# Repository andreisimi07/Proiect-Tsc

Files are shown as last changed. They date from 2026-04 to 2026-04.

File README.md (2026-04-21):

# InkTime

Acest repository contine fisierele de design hardware, documentatia si detaliile de implementare pentru smartwatch. Inima sistemului este nRF52840 de la Nordic Semiconductor, ales pentru capabilitatile sale multiprotocol (Bluetooth LE, Thread, Zigbee) si consumul redus de energie.

## Schema Bloc

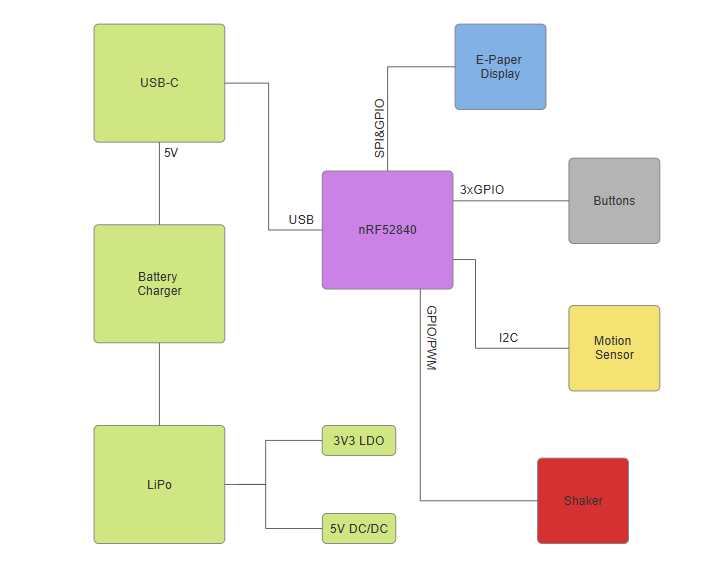
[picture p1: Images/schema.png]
Schema bloc


## Bill of Materials (BOM)

| Component | Description | Qty | Manufacturer | Part Number | Datasheet |
| :--- | :--- | :--- | :--- | :--- | :--- |
| **Microcontroller** | nRF52840 (AQFN-74) | 1 | Nordic Semiconductor | NRF52840_QF | [Link](https://files.seeedstudio.com/wiki/XIAO-BLE/Nano_BLE_MCU-nRF52840_PS_v1.1.pdf) |
| **Antenna** | 2.45GHz Chip Antenna | 1 | Johanson Technology | 2450AT18B100E | [Link](https://www.johansontechnology.com/datasheets/2450AT18B100.pdf) |
| **Accelerometer** | Triaxial low-g 12bit Sensor | 1 | Bosch Sensortec | BMA423 | [Link](https://watchy.sqfmi.com/assets/files/BST-BMA423-DS000-1509600-950150f51058597a6234dd3eaafbb1f0.pdf) |
| **Battery Charger** | Li-Ion/Polymer Charger IC | 1 | Texas Instruments | BQ25180YBGR | [Link](https://www.ti.com/product/BQ25180) |
| **Haptic Driver** | Driver for ERM/LRA | 1 | Texas Instruments | DRV2605YZFR | [Link](https://www.ti.com/product/DRV2605) |
| **Voltage Regulator** | Buck-Boost DC-DC | 1 | Richtek | RT6160AWSC | [Link](https://www.richtek.com/Products/Switching%20Regulators/Buck-Boost%20Converter/RT6160A) |
| **Fuel Gauge** | 1-Cell/2-Cell Fuel Gauge | 1 | Analog Devices | MAX17048G+T10 | [Link](https://www.analog.com/en/products/max17048.html) |
| **Connector (FPC)** | 0.5mm FPC RA SMT 24Ckt | 1 | Molex | 503480-2400 | [Link](https://www.molex.com/en-us/products/part-detail/5034802400) |
| **Connector (USB)** | USB Type-C 16-pin | 1 | Kinghelm | KH-TYPE-C-16P | [Link](https://jlcpcb.com/api/file/downloadByFileSystemAccessId/8588905154556923904) |
| **ESD Protection** | Low Cap. ESD Protection | 1 | STMicroelectronics | USBLC6-2SC6Y | [Link](https://www.st.com/en/protection-devices/usblc6-2.html) |
| **MOSFET (P)** | P-channel 20V/4.2A | 1 | Diodes Inc. | DMG2305UX-7 | [Link](https://www.lcsc.com/datasheet/C469327.pdf) |
| **MOSFET (N)** | N-channel 30V 1.5A | 1 | Vishay Siliconix | SI1308EDL-T1-GE3 | [Link](https://www.lcsc.com/datasheet/C469327.pdf) |
| **Schottky Diode** | 30V 0.5A Schottky | 3 | ON Semiconductor | MBR0530 | [Link](https://www.onsemi.com/pdf/datasheet/mbr0530t1-d.pdf) |
| **Inductor** | SMD Inductor 0.47µH | 1 | TDK | FTC252012SR47MBCA | [Link](https://jlcpcb.com/partdetail/6763488-FTC252012SR47MBCA/C5832368) |
| **Inductor** | Power Inductor 68uH | 1 | Wurth Electronics | 744043680 | [Link](https://www.we-online.com/en/components/products/WE-TPC) |
| **Switches** | Tactile Switches | 3 | Panasonic | EVP-AKE31A | [Link](https://wmsc.lcsc.com/wmsc/upload/file/pdf/v2/lcsc/2301111010_PANASONIC-EVPAKE31A_C569760.pdf) |
| **Crystals** | 32MHz & 32.768kHz | 2 | Generic/Nordic | X1, X2 | [Link1](https://wmsc.lcsc.com/wmsc/upload/file/pdf/v2/lcsc/2312080231_NDK-NX2016SA-32MHZ-EXS00A-CS11336_C6134317.pdf), [Link2](https://jlcpcb.com/partdetail/SeikoEpson-FC_135_32_7680KAA3/C2650472) |
| **Test Connector** | CABLE ADAPTER 6 POS | 1 | Tag Connect | TC2030-IDC | [Link](https://www.tag-connect.com/wp-content/uploads/bsk-pdf-manager/2019/12/TC2030-IDC-Datasheet-Rev-B.pdf) |

## nRF52840 Pin Mapping

| Pin nRF52840 | Signal | Component | Interface |
|---|---|---|---|
| P0.00/XL1 | XL1 | Crystal X2 (32.768kHz) | XTAL |
| P0.01/XL2 | XL2 | Crystal X2 (32.768kHz) | XTAL |
| P0.05/AIN3  | EPD_CS | E-Paper (J1 FPC) | SPI CS |
| P0.06 | SDA | BMA423, BQ25180, MAX17048, DRV2605 | I2C SDA |
| P0.07 | SCL | BMA423, BQ25180, MAX17048, DRV2605 | I2C SCL |
| P0.08 | IMU_INT1 | BMA423 | GPIO Input |
| P1.08 | IMU_INT2 | BMA423 | GPIO Input |
| P0.11 | PMIC_INT | BQ25180 | GPIO Input |
| P0.12 | HAPTIC_EN  | DRV2605 | GPIO |
| VBUS | VBUS | USB-C (J4) | Power |
| D- | D- | USB-C (J4) / USBLC6 | USB |
| D+ | D+ | USB-C (J4) / USBLC6 | USB |
| P0.13 | SW_UP | Buton Up | GPIO Input |
| P0.14 | SW_ENT | Buton Enter | GPIO Input |
| P0.15 | EPD_DC | E-Paper (J1 FPC) | SPI DC |
| P0.16 | EPD_RST | E-Paper (J1 FPC) | GPIO |
| P0.17 | EPD_BUSY | E-Paper (J1 FPC) | GPIO Input |
| P0.18/RESET | RESET | TC2030-IDC | SWD/GPIO |
| SWDCLK | SWDCLK | TC2030-IDC | SWD |
| SWDIO | SWDIO | TC2030-IDC | SWD |
| P1.02 | SW_DN | Buton Down | GPIO Input |
| P0.10/NFC2  | ALERT | MAX17048 | GPIO Input |
| ANT | RF | Antena 2450AT18B100E | RF |
| P0.02/AIN0  | SCK | E-Paper (J1 FPC) | SPI SCK |
| P0.03/AIN1  | MOSI | E-Paper (J1 FPC) | SPI MOSI |

## Arhitectura Sistemului

### 1. Microcontroler (MCU)
- **Chip:** Nordic nRF52840 (Cortex-M4F @ 64MHz)
- **Memorie:** 1MB Flash, 256KB RAM
- **Radio:** Bluetooth 5.4 Low Energy cu antena ceramica integrata
- **Oscilatoare:** 32MHz (operare) si 32.768kHz (sleep mode/RTC)

### 2. Managementul Energiei
- **Incarcator Li-Po:** BQ25180 (control prin I2C, curent programabil)
- **Regulator Voltaj:** RT6100 Buck-Boost (iesire stabila de 3.3V)
- **Monitorizare Baterie:** MAX17048 Fuel Gauge (algoritm ModelGauge)
- **Interfata Incarcare:** USB-C cu protectie USBLC6-2 ESD

### 3. Display (E-Paper)
- **Tip:** Electronic Paper Display (EPD)
- **Interfata:** SPI + Control Power Gating (PWR_EPD)
- **Circuit Drive:** Convertor Boost integrat pe placa (Diode MBR0530, L5 10uH) pentru generare VGH/VGL

### 4. Senzori si Feedback
- **IMU:** BMA421 (Accelerometru ultra-low power conectat prin I2C)
- **Haptic:** DRV2605 (Driver de vibratii cu librarie de efecte integrata via I2C)
- **Input:** 3 butoane mecanice (UP, ENTER, DOWN) cu circuite de filtrare

### 5. Interfete de Comunicatie (Mapare I2C)
| Componenta | Functie | Interfata |
| :--- | :--- | :--- |
| **BMA421** | Senzor Miscare | I2C |
| **MAX17048** | Status Baterie | I2C |
| **DRV2605** | Motor Vibratii | I2C |
| **BQ25180** | Incarcare | I2C |

## Debug si Programare
- **SWD:** Programare si depanare prin conector Tag-Connect TC2030
- **USB:** Comunicatie seriala si incarcare

## Consum de Energie si Autonomie

Dispozitivul este optimizat pentru functionare ultra-low power, utilizand starile de sleep ale nRF52840 si tehnica de power-gating pentru perifericele de inalta tensiune.

### Consum de Curent Estimat
| Mod Operare | Componente Active | Curent Estimat |
| :--- | :--- | :--- |
| **Deep Sleep** | MCU (System OFF), Fuel Gauge (Sleep) | ~10 µA |
| **Standby (Idle)** | MCU (System ON), IMU (Low-power) | ~0.8 mA |
| **EPD Refresh** | MCU, EPD Boost Circuit, Display | ~12 mA (peak) |
| **Haptic Alert** | MCU, Haptic Driver + Motor | ~80 mA (peak) |

### Estimarea Autonomiei Bateriei
Bazat pe o baterie Li-Po de **200mAh**:
- **Timp Static (Always-on):** Peste 1 an (EPD retine imaginea fara curent).
- **Utilizare Tipica:** ~10-12 zile (cu BLE activ si 1 refresh/ora).
- **Utilizare Intensa:** ~4-5 zile (notificari haptice si update-uri dese).

## Design Log

Aceasta sectiune descrie procesul de proiectare a PCB-ului, deciziile luate in timpul implementarii si modul in care proiectul respecta constrangerile de design impuse.

### Strategia de Plasare a Componentelor 

Procesul de layout a inceput cu plasarea componentelor constranse mecanic si a celor critice, precum:
- **Conectorul USB-C**
- **Butoanele laterale**
- **Conectorul pentru afisajul E-paper (FPC)**
- **Microcontrolerul nRF52840**

Aceste componente au fost pozitionate in concordanta cu carcasa mecanica pentru a asigura alinierea corecta si usurinta in utilizare.

Toate componentele au fost plasate **exclusiv pe stratul TOP**, conform cerintelor proiectului. Componentele pasive (rezistente, condensatoarele) au fost ulterior distribuite in jurul circuitelor integrate corespunzatoare, minimizand lungimea traseelor si asigurand o decuplare adecvata.

O atentie deosebita a fost acordata **condensatoarelor de decuplare de 100nF**, care au fost plasate cat mai aproape posibil de pinii de alimentare ai fiecarui circuit integrat.

### Strategia de Rutare 

Rutarea a fost efectuata pe un stack-up de **PCB cu 2 straturi**, structurat astfel:
- **Top Layer** – plasarea componentelor, rutarea semnalelor, traseelor de putere + plan de ground.
- **Bottom Layer** – rutarea semnalelor si traseelor de putere + plan de ground.

Reguli de design aplicate:
- **Trasee de alimentare:** latime ≥ 0.3 mm.
- **Trasee de semnal:** latime ≥ 0.15 mm.
- **Unghiuri:** Nu s-au folosit unghiuri de 90° (doar rutare lina sau la 45°).

### Planurile si ground

A fost implementata o strategie solida de legare la masa folosind zone de cupru (polygon pours) pe straturile de masa.
- Planurile de masa au fost aplicate pe ambele straturi.

### Consideratii RF si Antena

Zona antenei a fost tratata ca o zona de restrictie stricta plasata in coltul placii:
- Fara cupru.
- Fara trasee.
- Fara treceri (vias).

### Consideratii inductoare
Inductoarele L2 si L3 au fost plasate perpendicular pentru a diminua interferenta campurilor magnetice produse de acestea.

### Constrangeri ale Componentelor

Toate componentele respecta regulile de amprenta (footprint) solicitate:
- **Rezistente:** 0201.
- **Condensatori ≤ 100nF:** 0201.
- **Condensatori > 100nF:** 0402.

### Exceptii de la Regulile de Design (Acceptate)

**Dimensiunea Via-urilor**
Erorile raportate pentru dimensiunea gaurilor de trecere (via drill size) au fost verificate si aprobate manual.

## Continutul Repository-ului

### Proiectare (Design)
- **schematic.sch** – Fisierul de design al schemei electronice.
- **board.brd** – Fisierul pentru layout-ul PCB-ului.

### Productie (Manufacturing)
- **GerberFiles.zip** – Fisierele pentru fabricatia PCB-ului (Gerber + fisiere de gaurire).
- **bom.csv / bom.xlsx** – Lista de materiale (Bill of Materials).
- **pick&place.cpl** – Fisierul pentru plasarea automata a componentelor pe placa.

### Mecanica (Mechanical)
- **smartwatch_exploded_view.stp** – Vedere 3D explodata completa (PCB + baterie + ecran + carcasa).
- **smartwatch.stp** – Vedere 3D completa a dispozitivului.
- de exportat din autodesk fusion

### Imagini (Images)
- **pcb_2d.png** – Prezentare 2D a cablajului.
- **pcb_3d.png** – Vedere 3D a pcb
- **block_diagram.jpg** – Diagrama bloc a sistemului.
- **smartwatch_final.png** – Imagine cu produsul final.

### Licenta si Documentatie
- **LICENSE** – Fisierul cu licenta open-source a proiectului.
- **README.md** – Documentatia principala a proiectului.

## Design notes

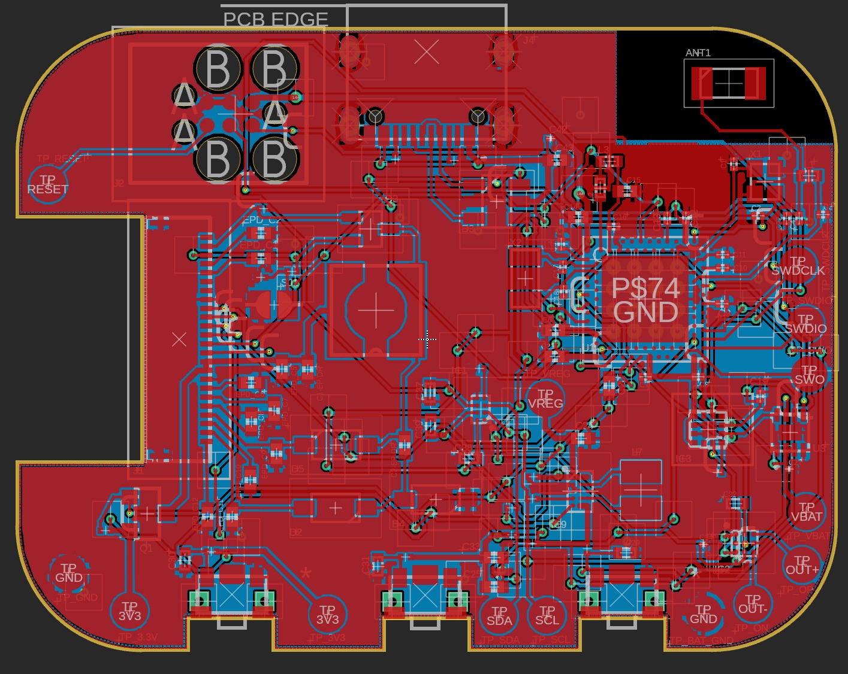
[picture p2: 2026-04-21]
Images/pcb2d.jpeg

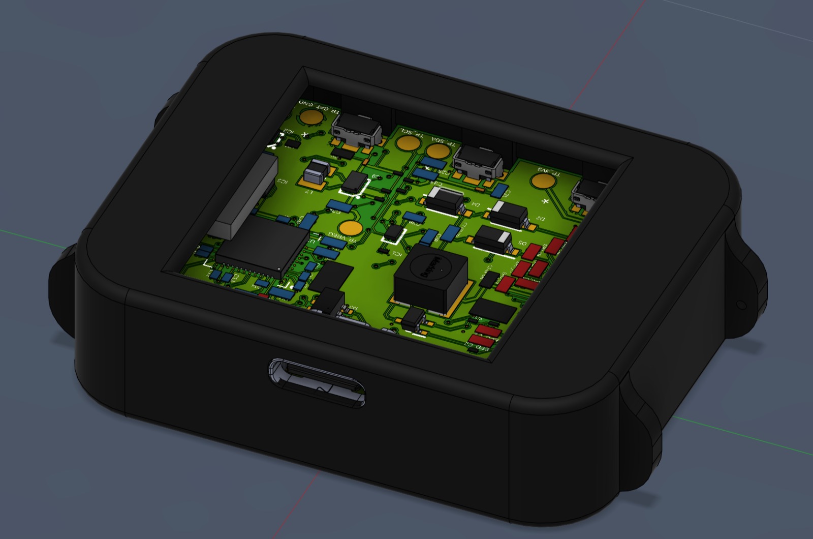
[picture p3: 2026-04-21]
Images/smartwatch.jpeg

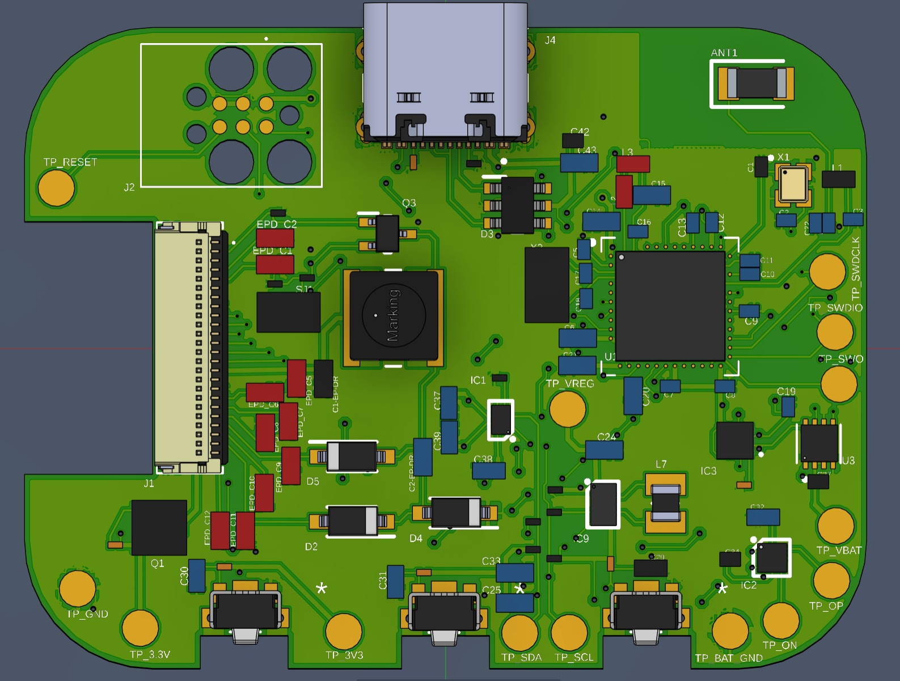
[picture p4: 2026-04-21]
Images/pcb3d.jpeg

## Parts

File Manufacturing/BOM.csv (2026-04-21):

Qty | Value | Device | Package | Parts | Description | ARROW_PART_NUMBER | ARROW_PRICE-STOCK | AVAILABILITY | CHECK_PRICES | COPYRIGHT | DESCRIPTION | DIGI-KEY_PART_NUMBER_1 | DIGI-KEY_PART_NUMBER_2 | DIGI-KEY_PART_NUMBER_3 | HEIGHT | JLCPCB | MANUFACTURER_NAME | MANUFACTURER_PART_NUMBER | MF | MFR_NAME | MOUSER_PART_NUMBER | MOUSER_PRICE-STOCK | MP | PACKAGE | POPULARITY | PRICE | PROD_ID | PURCHASE-URL | SNAPEDA_LINK | TP_SIGNAL_NAME | VALUE
1 | 0 | CPF0201D7K68C1_CPF0201D7K68C1 | CPF0201D7K68C1_0201 | R3 | 7.68k 0201 Thin Film Surface Mount Fixed Resistor +/-0.5% 0.031W CPF0201D7K68C1
2 | 0 | ERA-1AEB3401C_CPF0201D7K68C1 | ERA-1AEB3401C_0201 | R2, R4 | 7.68k 0201 Thin Film Surface Mount Fixed Resistor +/-0.5% 0.031W CPF0201D7K68C1
1 | 0 | ESP32_C6_LIBRARY_7_JUMPER_SJ | ESP32_C6_LIBRARY_7_JUMPER_SJ | SJ1 | SMD solder JUMPER |  |  |  |  |  |  |  |  |  |  |  |  |  |  |  |  |  |  |  | 3
1 | 0.1uF | GRM011R60J152KE01L_1_GRM011R60J152KE01L | GRM011R60J152KE01L_1_0201 | C23 | Check availability
3 | 0.1uF | GRM011R60J152KE01L_2_GRM011R60J152KE01L | GRM011R60J152KE01L_2_CAPC0201X13N | C27, C34, C42 | Check availability |  |  | In Stock | https://www.snapeda.com/parts/GRM011R60J152KE01L/Murata/view-part/?ref=eda |  | SMD Capacitor X5R(EIA) with Capacitance: 1500pF Tol. 10%. Rated Voltage: 6.3Vdc |  |  |  |  |  |  |  | Murata |  |  |  | GRM011R60J152KE01L | 0201 Murata |  | None |  |  | https://www.snapeda.com/parts/GRM011R60J152KE01L/Murata/view-part/?ref=snap
1 | 0.47 | ERA-1AEB3401C_CPF0201D7K68C1 | ERA-1AEB3401C_0201 | R1_EP_DR | 7.68k 0201 Thin Film Surface Mount Fixed Resistor +/-0.5% 0.031W CPF0201D7K68C1
1 | 1.0uF | PERFECT_0402_CAP_0402 | PERFECT_0402_0402 | C15 | 0402 (1005 Metric)
5 | 100nF | NORDIC_NRF_3_CAPACITOR_0201_L | NORDIC_NRF_3_RESC0201_L | C5, C7, C8, C12, C19 | Generic chip capacitor
1 | 100pF | NORDIC_NRF_3_CAPACITOR_0201_L | NORDIC_NRF_3_RESC0201_L | C11 | Generic chip capacitor
1 | 10K | CPF0201D7K68C1_CPF0201D7K68C1 | CPF0201D7K68C1_0201 | R_PWR_EPD | 7.68k 0201 Thin Film Surface Mount Fixed Resistor +/-0.5% 0.031W CPF0201D7K68C1
2 | 10K | ERA-1AEB3401C_CPF0201D7K68C1 | ERA-1AEB3401C_0201 | R2_EP_DR, R9 | 7.68k 0201 Thin Film Surface Mount Fixed Resistor +/-0.5% 0.031W CPF0201D7K68C1
3 | 10k | CPF0201D7K68C1_CPF0201D7K68C1 | CPF0201D7K68C1_0201 | R5, R7, R8 | 7.68k 0201 Thin Film Surface Mount Fixed Resistor +/-0.5% 0.031W CPF0201D7K68C1
1 | 10uF | NORDIC_NRF_3_CAPACITOR_0402_L | NORDIC_NRF_3_RESC0402_L | C39 | Generic chip capacitor
2 | 10uF | PERFECT_0402_CAP_0402 | PERFECT_0402_0402 | C1-EP-DR, C24 | 0402 (1005 Metric)
1 | 10uH | NORDIC_NRF_2_INDUCTOR_0402_L | NORDIC_NRF_2_RESC0402_L | L2 | Generic chip inductor
4 | 12pF | NORDIC_NRF_3_CAPACITOR_0201_L | NORDIC_NRF_3_RESC0201_L | C1, C2, C17, C18 | Generic chip capacitor
1 | 15nH | NORDIC_NRF_2_INDUCTOR_0402_L | NORDIC_NRF_2_RESC0402_L | L3 | Generic chip inductor
2 | 1pF | NORDIC_NRF_3_CAPACITOR_0201_L | NORDIC_NRF_3_RESC0201_L | C3, C4 | Generic chip capacitor
6 | 1uF | NORDIC_NRF_3_CAPACITOR_0402_L | NORDIC_NRF_3_RESC0402_L | C29, C30, C31, C32, C37, C38 | Generic chip capacitor
10 | 1uF/50V | PERFECT_0402_CAP_0402 | PERFECT_0402_0402 | EPD_C1, EPD_C2, EPD_C5, EPD_C6, EPD_C7, EPD_C8, EPD_C9, EPD_C10, EPD_C11, EPD_C12 | 0402 (1005 Metric)
1 | 2.2 | ERA-1AEB3401C_CPF0201D7K68C1 | ERA-1AEB3401C_0201 | R_TYPE_SEL | 7.68k 0201 Thin Film Surface Mount Fixed Resistor +/-0.5% 0.031W CPF0201D7K68C1
3 | 2025-10-22_07-23-44_LIBRARY_EVP-AKE31ASW_EVP-AKE31A_PAN | 2025-10-22_07-23-44_LIBRARY_EVP-AKE31ASW_EVP-AKE31A_PAN | 2025-10-22_07-23-44_LIBRARY_SW_EVP-AKE31A_PAN | SW_DN, SW_ENT, SW_UP |  |  |  |  |  | Copyright (C) 2025 Ultra Librarian. All rights reserved. |  | P123437TR-ND | P123437CT-ND | P123437DKR-ND |  |  | Panasonic | EVP-AKE31A
2 | 22uF | PERFECT_0402_CAP_0402 | PERFECT_0402_0402 | C25, C33 | 0402 (1005 Metric)
1 | 2450AT18B100E_2450AT18B100E | 2450AT18B100E_2450AT18B100E | 2450AT18B100E_ANTC3216X140N | ANT1 | Antennas 2.45GHz ANTENNA | 2450AT18B100E | https://www.arrow.com/en/products/2450at18b100e/johanson-dielectrics?utm_currency=USD&region=nac |  |  |  | Antennas 2.45GHz ANTENNA |  |  |  | 1.4mm |  | JOHANSON TECHNOLOGY | 2450AT18B100E |  |  | 609-2450AT18B100E | https://www.mouser.co.uk/ProductDetail/Johanson-Technology/2450AT18B100E?qs=yCnrNFeXz%252Bh5MFsFIXGZGA%3D%3D
1 | 3.9nH | NORDIC_NRF_2_INDUCTOR_0402_L | NORDIC_NRF_2_RESC0402_L | L1 | Generic chip inductor
1 | 32.768kHz | NORDIC_NRF_1_XTAL_32KHZ | NORDIC_NRF_1_XTAL_3215_N | X2
1 | 32MHz | NORDIC_NRF_XTAL_32MHZ | NORDIC_NRF_BT-XTAL_2016_N | X1
2 | 3K3 | ERA-1AEB3401C_CPF0201D7K68C1 | ERA-1AEB3401C_0201 | R17, R18 | 7.68k 0201 Thin Film Surface Mount Fixed Resistor +/-0.5% 0.031W CPF0201D7K68C1
5 | 4.7uF | PERFECT_0402_CAP_0402 | PERFECT_0402_0402 | C6, C14, C20, C21, C43 | 0402 (1005 Metric)
1 | 4.7uF/25V | PERFECT_0402_CAP_0402 | PERFECT_0402_0402 | C2-EP-DR | 0402 (1005 Metric)
1 | 47nF | NORDIC_NRF_3_CAPACITOR_0201_L | NORDIC_NRF_3_RESC0201_L | C16 | Generic chip capacitor
1 | 503480-2400 | 503480-2400_503480-2400 | 503480-2400_5034802400 | J1 | FFC & FPC Connectors 0.5mm FPC RA SMT Dual Contact 24Ckt |  |  |  |  |  | FFC & FPC Connectors 0.5mm FPC RA SMT Dual Contact 24Ckt |  |  |  | 1.87mm |  | Molex | 503480-2400 |  |  | 538-503480-2400 | https://www.mouser.co.uk/ProductDetail/Molex/503480-2400?qs=OAhjpuo3Vu7efIoxFh9AOw%3D%3D
2 | 5K1 | CPF0201D7K68C1_CPF0201D7K68C1 | CPF0201D7K68C1_0201 | R1_USB, R2_USB | 7.68k 0201 Thin Film Surface Mount Fixed Resistor +/-0.5% 0.031W CPF0201D7K68C1
1 | 68 uH | ESP32_C6_LIBRARY_2_744043680IND_4828-WE-TPC_WRE | ESP32_C6_LIBRARY_2_IND_4828-WE-TPC_WRE | L5 |  |  |  |  |  | Copyright (C) 2024 Ultra Librarian. All rights reserved. |  |  |  |  |  |  |  | 744043680 |  | Wurth Electronics
1 | 820pF N.C. | NORDIC_NRF_3_CAPACITOR_0201_L | NORDIC_NRF_3_RESC0201_L | C9 | Generic chip capacitor
1 | BMA423 | BMA423_BMA423 | BMA423_BMA423 | IC3 | Accelerometers Triaxial low-g 12bit Acceleration Sensor | BMA423 | https://www.arrow.com/en/products/bma423/bosch |  |  |  | Accelerometers Triaxial low-g 12bit Acceleration Sensor |  |  |  | 1mm |  | BOSCH | BMA423 |  |  | 262-BMA423 | https://www.mouser.co.uk/ProductDetail/Bosch-Sensortec/BMA423?qs=HXFqYaX1Q2xC%252BSgeGoX3mg%3D%3D
1 | BQ25180YBGR | BQ25180YBGR_BQ25180YBGR | BQ25180YBGR_BGA8C40P2X4_100X155X50 | IC1 | Charger IC Lithium Ion/Polymer, Lithium Iron Phosphate 8-DSBGA (1.6x1.1) | BQ25180YBGR | https://www.arrow.com/en/products/bq25180ybgr/texas-instruments?utm_currency=USD&region=nac |  |  |  | Charger IC Lithium Ion/Polymer | Lithium Iron Phosphate 8-DSBGA (1.6x1.1) |  |  |  | 0.5mm |  | Texas Instruments | BQ25180YBGR |  |  | 595-BQ25180YBGR | https://www.mouser.co.uk/ProductDetail/Texas-Instruments/BQ25180YBGR?qs=doiCPypUmgEWjAK%252BJAX6Tw%3D%3D
1 | DMG2305UX-7 20V/4.2A/52mO/1.4W | ESP32_C6_LIBRARY_4_ESP32_WROVER_SPARKFUN-DISCRETESEMI_MOSFET_PCH-DMG2305UX-7 | ESP32_C6_LIBRARY_4_ESP32_C6_LIBRARY_4_ESP32_C6_LIBRARY_4_ESP32_C6_LIBRARY_4_ESP32_WROVER_SPARKFUN-DISCRETESEMI_SOT23-3 | Q1 | P-channel MOSFETs |  |  |  |  |  |  |  |  |  |  |  |  |  |  |  |  |  |  |  |  |  | TRAN-14388 |  |  |  | 20V/4.2A/52mO/1.4W
1 | DRV2605YZFR | DRV2605YZFR_DRV2605YZFR | DRV2605YZFR_BGA9C50P3X3_144X144X62 | IC2 | Haptic Driver for ERM/LRA with Built-In Library and Smart Loop Architecture | DRV2605YZFR | https://www.arrow.com/en/products/drv2605yzfr/texas-instruments?region=nac |  |  |  | Haptic Driver for ERM/LRA with Built-In Library and Smart Loop Architecture |  |  |  | 0.625mm |  | Texas Instruments | DRV2605YZFR
1 | FTC252012SR47MBCA | MLP2016SR47MT0S1_FTC252012SR47MBCA | MLP2016SR47MT0S1_INDC2016X100N | L7 | SMD / SMT Inductors (Coils), L=0.47?H, L x W x T : |  |  |  |  |  | SMD / SMT Inductors (Coils) | L=0.47?H | L x W x T : |  |  |  | 1mm | https://jlcpcb.com/partdetail/6763488-FTC252012SR47MBCA/C5832368 | TDK | FTC252012SR47MBCA
14 | HECTOR_WATCH_1_TPTP20R | HECTOR_WATCH_1_TPTP20R | HECTOR_WATCH_1_TP20R | TP_3.3V, TP_3V3, TP_BAT_GND, TP_GND, TP_ON, TP_OP, TP_RESET, TP_SCL, TP_SDA, TP_SWDCLK, TP_SWDIO, TP_SWO, TP_VBAT, TP_VREG | Test pad |  |  |  |  |  |  |  |  |  |  |  |  |  |  |  |  |  |  |  | 2
1 | KH-TYPE-C-16P | KH-TYPE-C-16P_KH-TYPE-C-16P | KH-TYPE-C-16P_KINGHELM_KH-TYPE-C-16P | J4 | Check availability |  |  | Not in stock | https://www.snapeda.com/parts/KH-TYPE-C-16P/Kinghelm/view-part/?ref=eda |  |  |  |  |  |  |  |  |  | kinghelm |  |  |  | KH-TYPE-C-16P | None |  | None |  |  | https://www.snapeda.com/parts/KH-TYPE-C-16P/Kinghelm/view-part/?ref=snap
1 | MAX17048G+T10 | ESP32_C6_LIBRARY_MAX17048G+T10 | ESP32_C6_LIBRARY_SON50P200X200X80-9N | U3 | Check availability |  |  | In Stock | https://www.snapeda.com/parts/MAX17048G+T10/Analog+Devices/view-part/?ref=eda |  | 3µA 1-Cell/2-Cell Fuel Gauge with ModelGauge |  |  |  |  |  |  |  | Analog Devices |  |  |  | MAX17048G+T10 | TDFN-8 Maxim |  | None |  | https://www.snapeda.com/api/url_track_click_mouser/?unipart_id=329239&manufacturer=Analog Devices&part_name=MAX17048G+T10&search_term=None | https://www.snapeda.com/parts/MAX17048G+T10/Analog+Devices/view-part/?ref=snap
3 | MBR0530 | ESP32_C6_LIBRARY_5_MBR0530 | ESP32_C6_LIBRARY_5_SOD3716X135N | D2, D4, D5 | ON SEMICONDUCTOR - MBR0530 - DIODE, SCHOTTKY, 0.5A, 30V, SOD-123 |  |  | In Stock | https://www.snapeda.com/parts/MBR0530/Onsemi/view-part/?ref=eda |  | Diode Schottky 30 V 500mA Surface Mount SOD-123 |  |  |  |  |  |  |  | ON Semiconductor |  |  |  | MBR0530 | SOD-123-2 ON Semiconductor |  | None |  | https://www.snapeda.com/api/url_track_click_mouser/?unipart_id=179458&manufacturer=ON Semiconductor&part_name=MBR0530&search_term=None | https://www.snapeda.com/parts/MBR0530/Onsemi/view-part/?ref=snap
3 | N.C. | NORDIC_NRF_3_CAPACITOR_0201_L | NORDIC_NRF_3_RESC0201_L | C10, C13, C22 | Generic chip capacitor
1 | NRF52840_QF | NORDIC_NRF_4_NRF52840_QF | NORDIC_NRF_4_AQFN50P700X700X85_HS-74N | U1 | nRF52840
1 | RT6160AWSC | RT6160AWSC_RT6160AWSC | RT6160AWSC_BGA15C40P3X5_140X230X60 | IC9 | Buck-Boost Regulator Positive Output Step-Up/Step-Down I2C DC-DC Controller IC 15-WL-CSP (BSC) (1.4x2.3) |  |  |  |  |  | Buck-Boost Regulator Positive Output Step-Up/Step-Down I2C DC-DC Controller IC 15-WL-CSP (BSC) (1.4x2.3) |  |  |  | 0.6mm |  | RICHTEK | RT6160AWSC |  |  | 835-RT6160AWSC | https://www.mouser.co.uk/ProductDetail/Richtek/RT6160AWSC?qs=amGC7iS6iy%2FLd9PSoixZXQ%3D%3D
1 | SI1308EDL-T1-GE3 | ESP32_C6_LIBRARY_6_SI1308EDL-T1-GE3 | ESP32_C6_LIBRARY_6_SOT65P210X110-3N | Q3 | MOSFET N-Ch 30V 1.5A TrenchFET SC70 Vishay Si1308EDL-T1-GE3 N-channel MOSFET Transistor, 1.5 A, 30 V, 3-Pin SC-70 |  |  | In Stock | https://www.snapeda.com/parts/SI1308EDL-T1-GE3/Vishay+Siliconix/view-part/?ref=eda |  | Si1308EDL-T1-GE3 N-channel MOSFET Transistor | 1.5 A | 30 V | 3-Pin SC-70 | Siliconix / Vishay SI1308EDL-T1-GE3 |  |  |  |  |  |  |  | Vishay Siliconix |  |  |  | SI1308EDL-T1-GE3 | SOT-323 Vishay Semiconductor |  | None |  | https://www.snapeda.com/api/url_track_click_mouser/?unipart_id=274603&manufacturer=Vishay Siliconix&part_name=SI1308EDL-T1-GE3&search_term=None
1 | TC2030-IDC | TC2030-IDC_TC2030-IDC | TC2030-IDC_TC2030IDC | J2 | CABLE ADAPTER 6 POS |  |  |  |  |  | CABLE ADAPTER 6 POS |  |  |  | 19mm |  | Tag Connect | TC2030-IDC
1 | USBLC6-2SC6Y | ESP32_C6_LIBRARY_3_USBLC6-2SC6Y | ESP32_C6_LIBRARY_3_SOT95P280X145-6N | D3 | Low Cap. ESD Protection Auto SOT-23-6 STMicroelectronics USBLC6-2SC6Y, Dual Uni-Directional TVS Diode Array, 6-Pin SOT-23 |  |  | In Stock | https://www.snapeda.com/parts/USBLC6-2SC6Y/STMicroelectronics/view-part/?ref=eda |  | 17V Clamp 5A (8/20µs) Ipp Tvs Diode Surface Mount SOT-23-6 |  |  |  |  |  |  |  | STMicroelectronics |  |  |  | USBLC6-2SC6Y | SOT-23-6 STMicroelectronics |  | None |  |  | https://www.snapeda.com/parts/USBLC6-2SC6Y/STMicroelectronics/view-part/?ref=snap

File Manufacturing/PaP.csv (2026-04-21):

ANT1 | 16.97 | 14.43 | 0.00 | 2450AT18B100E_2450AT18B100E | 2450AT18B100E_ANTC3216X140N
C1 | 17.25 | 9.88 | 90.00 | 12pF | NORDIC_NRF_3_RESC0201_L
C1-EP-DR | -6.67 | -1.69 | 270.00 | 10uF | PERFECT_0402_0402
C10 | 16.62 | 4.03 | 0.00 | N.C. | NORDIC_NRF_3_RESC0201_L
C11 | 16.63 | 4.76 | 0.00 | 100pF | NORDIC_NRF_3_RESC0201_L
C12 | 14.55 | 6.84 | 90.00 | 100nF | NORDIC_NRF_3_RESC0201_L
C13 | 13.51 | 6.82 | 90.00 | N.C. | NORDIC_NRF_3_RESC0201_L
C14 | 8.52 | 6.90 | 180.00 | 4.7uF | PERFECT_0402_0402
C15 | 11.27 | 8.34 | 0.00 | 1.0uF | PERFECT_0402_0402
C16 | 10.51 | 6.35 | 0.00 | 47nF | NORDIC_NRF_3_RESC0201_L
C17 | 7.65 | 4.07 | 90.00 | 12pF | NORDIC_NRF_3_RESC0201_L
C18 | 7.68 | 2.69 | 90.00 | 12pF | NORDIC_NRF_3_RESC0201_L
C19 | 18.72 | -3.21 | 90.00 | 100nF | NORDIC_NRF_3_RESC0201_L
C2 | 18.61 | 6.97 | 180.00 | 12pF | NORDIC_NRF_3_RESC0201_L
C2-EP-DR | -1.24 | -5.97 | 90.00 | 4.7uF/25V | PERFECT_0402_0402
C20 | 10.25 | -2.62 | 270.00 | 4.7uF | PERFECT_0402_0402
C21 | 7.20 | -0.96 | 180.00 | 4.7uF | PERFECT_0402_0402
C22 | 20.21 | 6.81 | 270.00 | N.C. | NORDIC_NRF_3_RESC0201_L
C23 | 5.99 | -7.75 | 90.00 | 0.1uF | GRM011R60J152KE01L_1_0201
C24 | 8.67 | -5.57 | 180.00 | 10uF | PERFECT_0402_0402
C25 | 3.78 | -13.93 | 0.00 | 22uF | PERFECT_0402_0402
C27 | 20.36 | -7.31 | 180.00 | 0.1uF | GRM011R60J152KE01L_2_CAPC0201X13N
C29 | 11.21 | -12.03 | 180.00 | 1uF | NORDIC_NRF_3_RESC0402_L
C3 | 22.26 | 7.02 | 0.00 | 1pF | NORDIC_NRF_3_RESC0201_L
C30 | -13.59 | -12.44 | 90.00 | 1uF | NORDIC_NRF_3_RESC0402_L
C31 | -2.73 | -12.78 | 90.00 | 1uF | NORDIC_NRF_3_RESC0402_L
C32 | 17.35 | -9.24 | 0.00 | 1uF | NORDIC_NRF_3_RESC0402_L
C33 | 3.79 | -12.28 | 0.00 | 22uF | PERFECT_0402_0402
C34 | 15.55 | -11.54 | 180.00 | 0.1uF | GRM011R60J152KE01L_2_CAPC0201X13N
C37 | 0.18 | -3.00 | 90.00 | 1uF | NORDIC_NRF_3_RESC0402_L
C38 | 2.37 | -6.71 | 0.00 | 1uF | NORDIC_NRF_3_RESC0402_L
C39 | 0.21 | -4.89 | 270.00 | 10uF | NORDIC_NRF_3_RESC0402_L
C4 | 20.93 | 6.82 | 270.00 | 1pF | NORDIC_NRF_3_RESC0201_L
C42 | 6.96 | 11.31 | 180.00 | 0.1uF | GRM011R60J152KE01L_2_CAPC0201X13N
C43 | 7.31 | 10.11 | 0.00 | 4.7uF | PERFECT_0402_0402
C5 | 7.56 | 5.37 | 90.00 | 100nF | NORDIC_NRF_3_RESC0201_L
C6 | 7.22 | 0.53 | 180.00 | 4.7uF | PERFECT_0402_0402
C7 | 12.27 | -2.10 | 180.00 | 100nF | NORDIC_NRF_3_RESC0201_L
C8 | 15.26 | -2.10 | 0.00 | 100nF | NORDIC_NRF_3_RESC0201_L
C9 | 16.59 | 2.01 | 0.00 | 820pF N.C. | NORDIC_NRF_3_RESC0201_L
D2 | -5.12 | -9.49 | 180.00 | MBR0530 | ESP32_C6_LIBRARY_5_SOD3716X135N
D3 | 3.94 | 7.76 | 0.00 | USBLC6-2SC6Y | ESP32_C6_LIBRARY_3_SOT95P280X145-6N
D4 | 0.51 | -9.02 | 180.00 | MBR0530 | ESP32_C6_LIBRARY_5_SOD3716X135N
D5 | -5.10 | -5.93 | 0.00 | MBR0530 | ESP32_C6_LIBRARY_5_SOD3716X135N
EPD_C1 | -9.31 | 4.55 | 180.00 | 1uF/50V | PERFECT_0402_0402
EPD_C10 | -9.90 | -7.92 | 90.00 | 1uF/50V | PERFECT_0402_0402
EPD_C11 | -10.94 | -9.99 | 90.00 | 1uF/50V | PERFECT_0402_0402
EPD_C12 | -12.31 | -9.98 | 90.00 | 1uF/50V | PERFECT_0402_0402
EPD_C2 | -9.31 | 5.99 | 180.00 | 1uF/50V | PERFECT_0402_0402
EPD_C5 | -8.13 | -1.67 | 90.00 | 1uF/50V | PERFECT_0402_0402
EPD_C6 | -9.86 | -2.44 | 180.00 | 1uF/50V | PERFECT_0402_0402
EPD_C7 | -8.58 | -4.02 | 90.00 | 1uF/50V | PERFECT_0402_0402
EPD_C8 | -9.84 | -4.63 | 270.00 | 1uF/50V | PERFECT_0402_0402
EPD_C9 | -8.45 | -6.44 | 90.00 | 1uF/50V | PERFECT_0402_0402
IC1 | 3.03 | -3.94 | 180.00 | BQ25180YBGR | BQ25180YBGR_BGA8C40P2X4_100X155X50
IC2 | 17.85 | -11.47 | 0.00 | DRV2605YZFR | DRV2605YZFR_BGA9C50P3X3_144X144X62
IC3 | 15.81 | -5.07 | 90.00 | BMA423 | BMA423_BMA423
IC9 | 8.62 | -8.56 | 0.00 | RT6160AWSC | RT6160AWSC_BGA15C40P3X5_140X230X60
J1 | -13.70 | 0.00 | 270.00 | 503480-2400 | 503480-2400_5034802400
J2 | -11.06 | 12.70 | 180.00 | TC2030-IDC | TC2030-IDC_TC2030IDC
J4 | 0.00 | 13.84 | 180.00 | KH-TYPE-C-16P | KH-TYPE-C-16P_KINGHELM_KH-TYPE-C-16P
L1 | 21.47 | 9.21 | 180.00 | 3.9nH | NORDIC_NRF_2_RESC0402_L
L2 | 9.76 | 8.52 | 90.00 | 10uH | NORDIC_NRF_2_RESC0402_L
L3 | 10.25 | 10.04 | 0.00 | 15nH | NORDIC_NRF_2_RESC0402_L
L5 | -2.85 | 1.63 | 180.00 | 68 uH | ESP32_C6_LIBRARY_2_IND_4828-WE-TPC_WRE
L7 | 12.02 | -8.48 | 270.00 | FTC252012SR47MBCA | MLP2016SR47MT0S1_INDC2016X100N
Q1 | -15.64 | -9.82 | 270.00 | DMG2305UX-7 20V/4.2A/52mΩ/1.4W | ESP32_C6_LIBRARY_4_ESP32_C6_LIBRARY_4_ESP32_C6_LIBRARY_4_ESP32_C6_LIBRARY_4_ESP32_WROVER_SPARKFUN-DISCRETESEMI_SOT23-3
Q3 | -3.16 | 6.21 | 0.00 | SI1308EDL-T1-GE3 | ESP32_C6_LIBRARY_6_SOT65P210X110-3N
R17 | 5.93 | -11.50 | 270.00 | 3K3 | ERA-1AEB3401C_0201
R18 | 4.78 | -11.01 | 90.00 | 3K3 | ERA-1AEB3401C_0201
R1_EP_DR | -7.56 | 3.82 | 90.00 | 0.47 | ERA-1AEB3401C_0201
R1_USB | 1.54 | 10.06 | 270.00 | 5K1 | CPF0201D7K68C1_0201
R2 | 4.78 | -9.50 | 270.00 | 0 | ERA-1AEB3401C_0201
R2_EP_DR | -9.15 | 7.36 | 270.00 | 10K | ERA-1AEB3401C_0201
R2_USB | -1.76 | 10.13 | 0.00 | 5K1 | CPF0201D7K68C1_0201
R3 | 16.31 | -7.49 | 90.00 | 0 | CPF0201D7K68C1_0201
R4 | 5.93 | -8.97 | 90.00 | 0 | ERA-1AEB3401C_0201
R5 | -12.08 | -11.95 | 90.00 | 10k | CPF0201D7K68C1_0201
R7 | 9.02 | -11.79 | 180.00 | 10k | CPF0201D7K68C1_0201
R8 | -1.18 | -12.27 | 90.00 | 10k | CPF0201D7K68C1_0201
R9 | 2.95 | -1.64 | 90.00 | 10K | ERA-1AEB3401C_0201
R_PWR_EPD | -18.04 | -10.76 | 90.00 | 10K | CPF0201D7K68C1_0201
R_TYPE_SEL | -9.32 | 3.50 | 90.00 | 2.2 | ERA-1AEB3401C_0201
SJ1 | -8.57 | 1.94 | 0.00 | 0 | ESP32_C6_LIBRARY_7_JUMPER_SJ
SW_DN | 10.96 | -14.00 | 180.00 | 2025-10-22_07-23-44_LIBRARY_EVP-AKE31ASW_EVP-AKE31A_PAN | 2025-10-22_07-23-44_LIBRARY_SW_EVP-AKE31A_PAN
SW_ENT | -0.08 | -14.03 | 180.00 | 2025-10-22_07-23-44_LIBRARY_EVP-AKE31ASW_EVP-AKE31A_PAN | 2025-10-22_07-23-44_LIBRARY_SW_EVP-AKE31A_PAN
SW_UP | -10.94 | -13.99 | 180.00 | 2025-10-22_07-23-44_LIBRARY_EVP-AKE31ASW_EVP-AKE31A_PAN | 2025-10-22_07-23-44_LIBRARY_SW_EVP-AKE31A_PAN
TP_3.3V | -16.68 | -15.30 | 0.00 | HECTOR_WATCH_1_TPTP20R | HECTOR_WATCH_1_TP20R
TP_3V3 | -5.56 | -15.49 | 0.00 | HECTOR_WATCH_1_TPTP20R | HECTOR_WATCH_1_TP20R
TP_BAT_GND | 15.56 | -15.46 | 0.00 | HECTOR_WATCH_1_TPTP20R | HECTOR_WATCH_1_TP20R
TP_GND | -20.11 | -13.14 | 0.00 | HECTOR_WATCH_1_TPTP20R | HECTOR_WATCH_1_TP20R
TP_ON | 18.33 | -14.90 | 0.00 | HECTOR_WATCH_1_TPTP20R | HECTOR_WATCH_1_TP20R
TP_OP | 21.09 | -12.70 | 0.00 | HECTOR_WATCH_1_TPTP20R | HECTOR_WATCH_1_TP20R
TP_RESET | -21.26 | 8.73 | 180.00 | HECTOR_WATCH_1_TPTP20R | HECTOR_WATCH_1_TP20R
TP_SCL | 6.76 | -15.55 | 0.00 | HECTOR_WATCH_1_TPTP20R | HECTOR_WATCH_1_TP20R
TP_SDA | 4.06 | -15.57 | 0.00 | HECTOR_WATCH_1_TPTP20R | HECTOR_WATCH_1_TP20R
TP_SWDCLK | 20.86 | 4.16 | 0.00 | HECTOR_WATCH_1_TPTP20R | HECTOR_WATCH_1_TP20R
TP_SWDIO | 21.28 | 0.87 | 0.00 | HECTOR_WATCH_1_TPTP20R | HECTOR_WATCH_1_TP20R
TP_SWO | 21.50 | -1.97 | 0.00 | HECTOR_WATCH_1_TPTP20R | HECTOR_WATCH_1_TP20R
TP_VBAT | 21.32 | -9.72 | 0.00 | HECTOR_WATCH_1_TPTP20R | HECTOR_WATCH_1_TP20R
TP_VREG | 6.67 | -3.34 | 0.00 | HECTOR_WATCH_1_TPTP20R | HECTOR_WATCH_1_TP20R
U1 | 12.28 | 2.27 | 0.00 | NRF52840_QF | NORDIC_NRF_4_AQFN50P700X700X85_HS-74N
U3 | 20.41 | -5.24 | 90.00 | MAX17048G+T10 | ESP32_C6_LIBRARY_SON50P200X200X80-9N
X1 | 19.00 | 8.88 | 270.00 | 32MHz | NORDIC_NRF_BT-XTAL_2016_N
X2 | 5.54 | 3.43 | 270.00 | 32.768kHz | NORDIC_NRF_1_XTAL_3215_N

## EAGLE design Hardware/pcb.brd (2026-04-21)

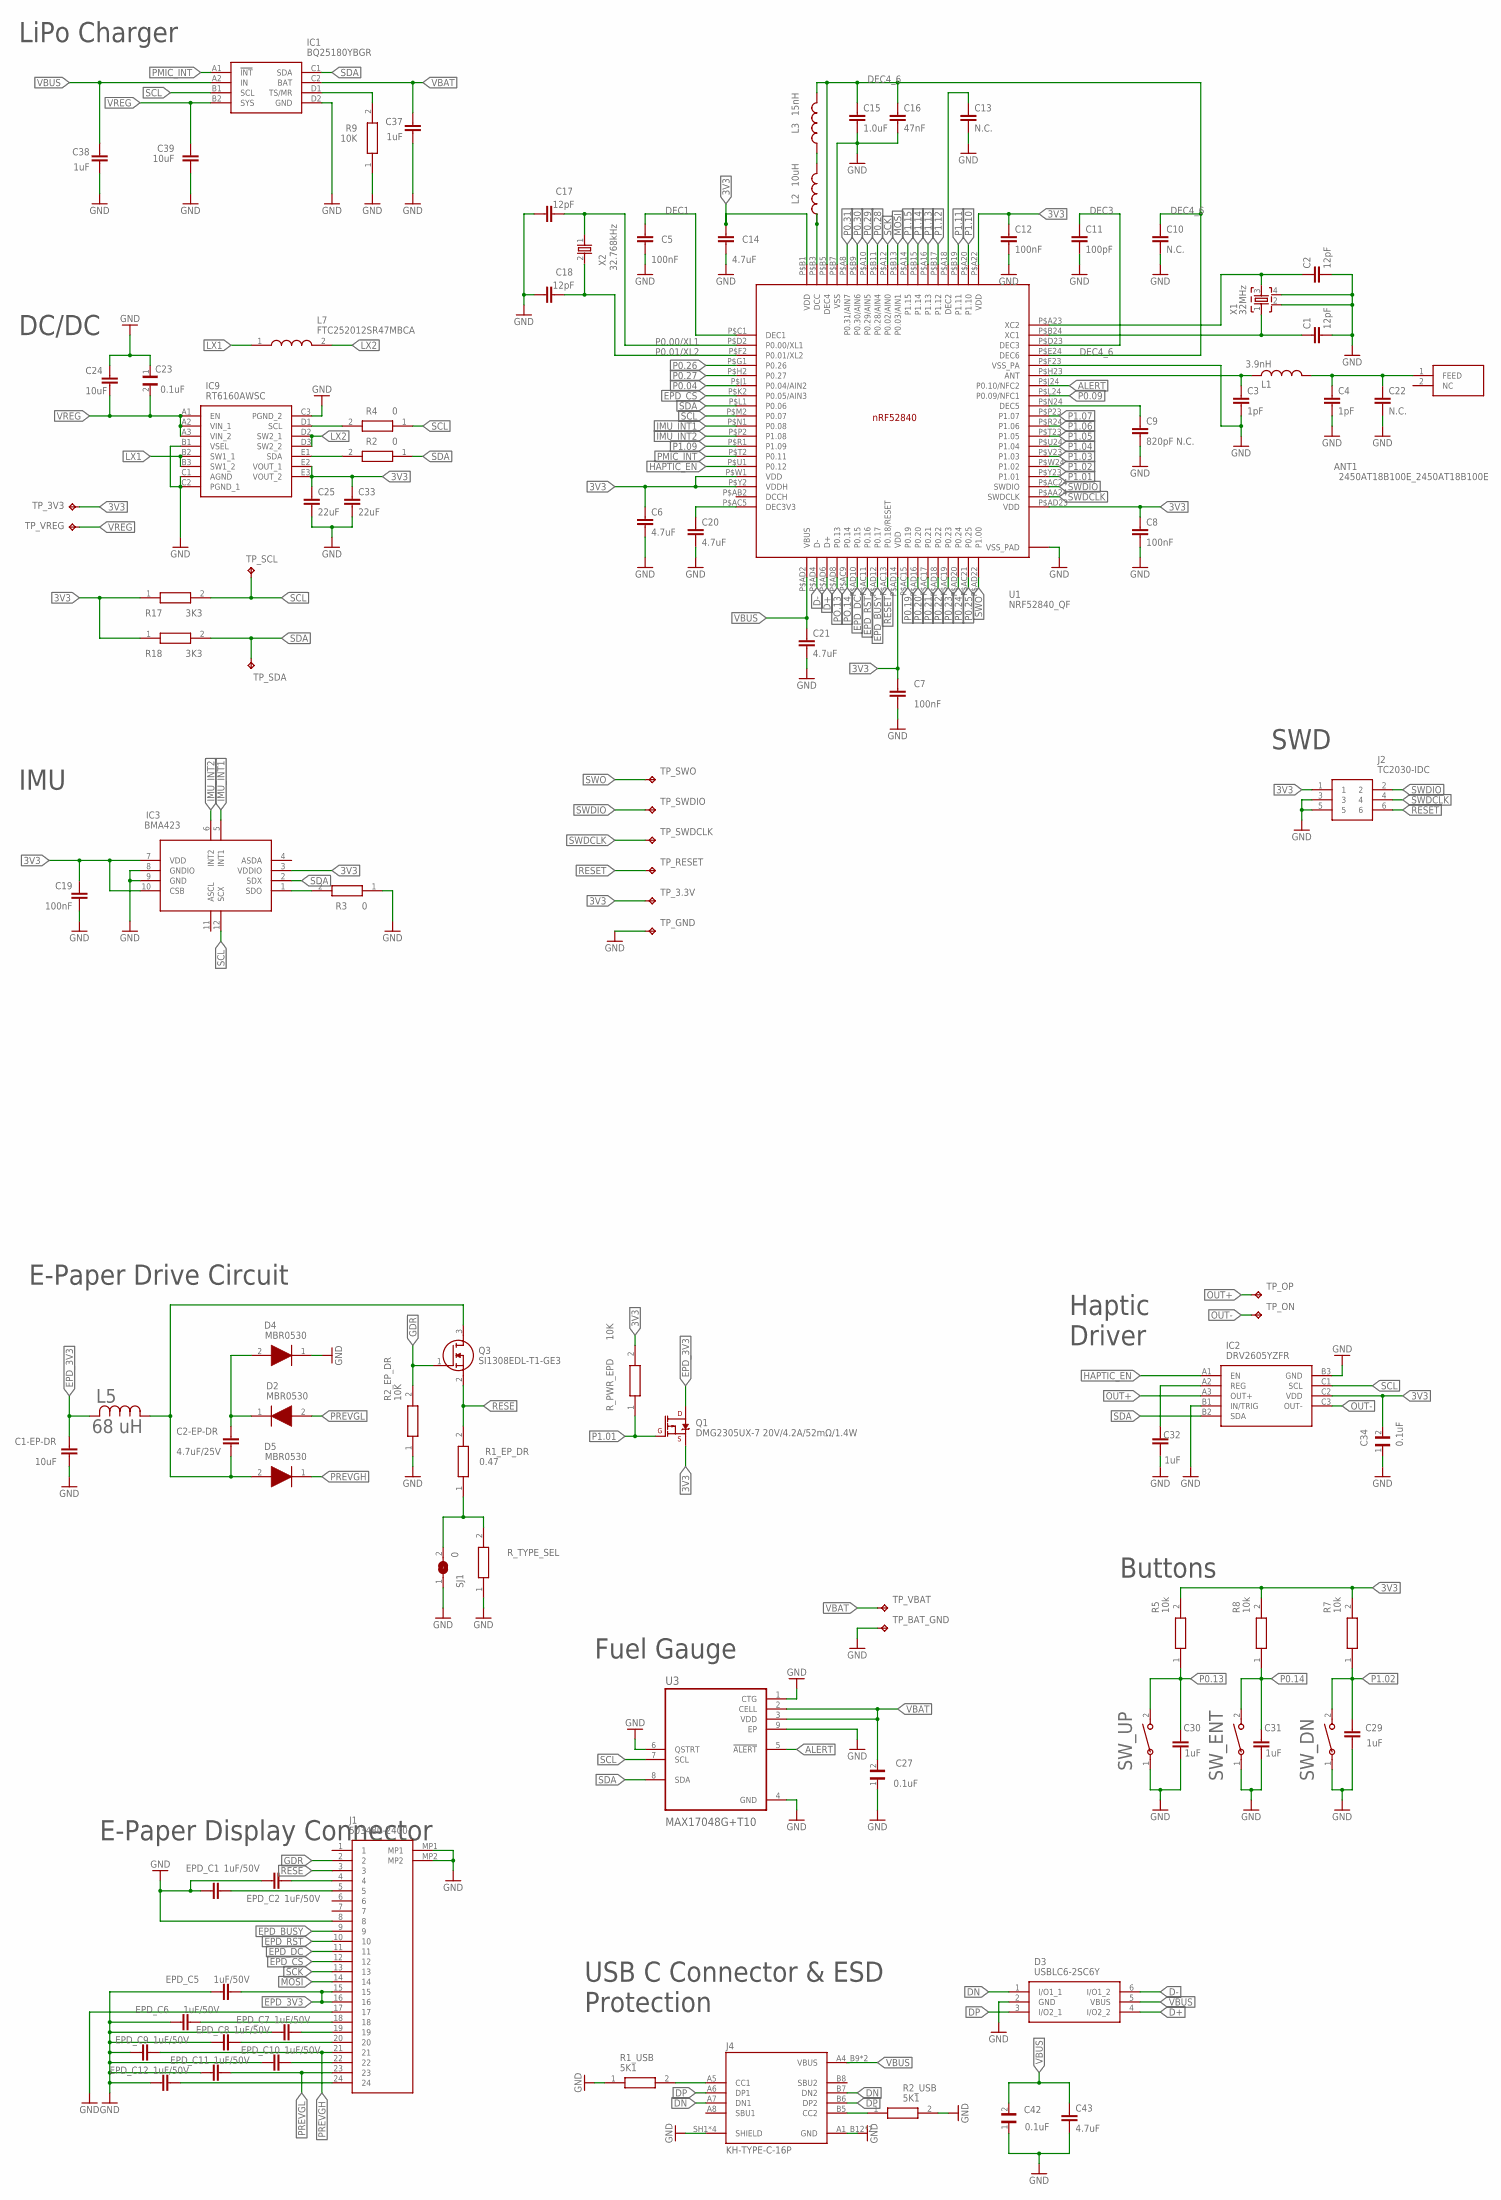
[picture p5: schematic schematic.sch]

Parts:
ANT1: 2450AT18B100E_2450AT18B100E; 2450AT18B100E_ANTC3216X140N
C1, C2, C17, C18: 12pF; NORDIC_NRF_3_RESC0201_L
C1-EP-DR, C24: 10uF; PERFECT_0402_0402
C2-EP-DR: 4.7uF/25V; PERFECT_0402_0402
C3, C4: 1pF; NORDIC_NRF_3_RESC0201_L
C5, C7, C8, C12, C19: 100nF; NORDIC_NRF_3_RESC0201_L
C6, C14, C20, C21, C43: 4.7uF; PERFECT_0402_0402
C9: 820pF N.C.; NORDIC_NRF_3_RESC0201_L
C10, C13, C22: N.C.; NORDIC_NRF_3_RESC0201_L
C11: 100pF; NORDIC_NRF_3_RESC0201_L
C15: 1.0uF; PERFECT_0402_0402
C16: 47nF; NORDIC_NRF_3_RESC0201_L
C23: 0.1uF; GRM011R60J152KE01L_1_0201
C25, C33: 22uF; PERFECT_0402_0402
C27, C34, C42: 0.1uF; GRM011R60J152KE01L_2_CAPC0201X13N
C29, C30, C31, C32, C37, C38: 1uF; NORDIC_NRF_3_RESC0402_L
C39: 10uF; NORDIC_NRF_3_RESC0402_L
D2, D4, D5: MBR0530; ESP32_C6_LIBRARY_5_SOD3716X135N
D3: USBLC6-2SC6Y; ESP32_C6_LIBRARY_3_SOT95P280X145-6N
EPD_C1, EPD_C2, EPD_C5, EPD_C6, EPD_C7, EPD_C8, EPD_C9, EPD_C10, EPD_C11, EPD_C12: 1uF/50V; PERFECT_0402_0402
IC1: BQ25180YBGR; BQ25180YBGR_BGA8C40P2X4_100X155X50
IC2: DRV2605YZFR; DRV2605YZFR_BGA9C50P3X3_144X144X62
IC3: BMA423; BMA423_BMA423
IC9: RT6160AWSC; RT6160AWSC_BGA15C40P3X5_140X230X60
J1: 503480-2400; 503480-2400_5034802400
J2: TC2030-IDC; TC2030-IDC_TC2030IDC
J4: KH-TYPE-C-16P; KH-TYPE-C-16P_KINGHELM_KH-TYPE-C-16P
L1: 3.9nH; NORDIC_NRF_2_RESC0402_L
L2: 10uH; NORDIC_NRF_2_RESC0402_L
L3: 15nH; NORDIC_NRF_2_RESC0402_L
L5: 68 uH; ESP32_C6_LIBRARY_2_IND_4828-WE-TPC_WRE
L7: FTC252012SR47MBCA; MLP2016SR47MT0S1_INDC2016X100N
Q1: DMG2305UX-7 20V/4.2A/52mΩ/1.4W; ESP32_C6_LIBRARY_4_ESP32_C6_LIBRARY_4_ESP32_C6_LIBRARY_4_ES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
Q3: SI1308EDL-T1-GE3; ESP32_C6_LIBRARY_6_SOT65P210X110-3N
R1_EP_DR: 0.47; ERA-1AEB3401C_0201
R1_USB, R2_USB: 5K1; CPF0201D7K68C1_0201
R2, R4: 0; ERA-1AEB3401C_0201
R2_EP_DR, R9: 10K; ERA-1AEB3401C_0201
R3: 0; CPF0201D7K68C1_0201
R5, R7, R8: 10k; CPF0201D7K68C1_0201
R17, R18: 3K3; ERA-1AEB3401C_0201
R_PWR_EPD: 10K; CPF0201D7K68C1_0201
R_TYPE_SEL: 2.2; ERA-1AEB3401C_0201
SJ1: 0; ESP32_C6_LIBRARY_7_JUMPER_SJ
SW_DN: 2025-10-22_07-23-44_LIBRARY_EVP-AKE31ASW_EVP-AKE3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; 2025-10-22_07-23-44_LIBRARY_SW_EVP-AKE31A_PAN
SW_ENT: 2025-10-22_07-23-44_LIBRARY_EVP-AKE31ASW_EVP-AKE3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; 2025-10-22_07-23-44_LIBRARY_SW_EVP-AKE31A_PAN
SW_UP: 2025-10-22_07-23-44_LIBRARY_EVP-AKE31ASW_EVP-AKE3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; 2025-10-22_07-23-44_LIBRARY_SW_EVP-AKE31A_PAN
TP_3.3V, TP_3V3: HECTOR_WATCH_1_TPTP20R; HECTOR_WATCH_1_TP20R
TP_BAT_GND: HECTOR_WATCH_1_TPTP20R; HECTOR_WATCH_1_TP20R
TP_GND: HECTOR_WATCH_1_TPTP20R; HECTOR_WATCH_1_TP20R
TP_ON: HECTOR_WATCH_1_TPTP20R; HECTOR_WATCH_1_TP20R
TP_OP: HECTOR_WATCH_1_TPTP20R; HECTOR_WATCH_1_TP20R
TP_RESET: HECTOR_WATCH_1_TPTP20R; HECTOR_WATCH_1_TP20R
TP_SCL: HECTOR_WATCH_1_TPTP20R; HECTOR_WATCH_1_TP20R
TP_SDA: HECTOR_WATCH_1_TPTP20R; HECTOR_WATCH_1_TP20R
TP_SWDCLK: HECTOR_WATCH_1_TPTP20R; HECTOR_WATCH_1_TP20R
TP_SWDIO: HECTOR_WATCH_1_TPTP20R; HECTOR_WATCH_1_TP20R
TP_SWO: HECTOR_WATCH_1_TPTP20R; HECTOR_WATCH_1_TP20R
TP_VBAT: HECTOR_WATCH_1_TPTP20R; HECTOR_WATCH_1_TP20R
TP_VREG: HECTOR_WATCH_1_TPTP20R; HECTOR_WATCH_1_TP20R
U1: NRF52840_QF; NORDIC_NRF_4_AQFN50P700X700X85_HS-74N
U3: MAX17048G+T10; ESP32_C6_LIBRARY_SON50P200X200X80-9N
X1: 32MHz; NORDIC_NRF_BT-XTAL_2016_N
X2: 32.768kHz; NORDIC_NRF_1_XTAL_3215_N

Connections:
3V3: C6.1, C7.1, C8.1, C12.1, C14.1, C19.1, C25.1, C33.1, C34.2, IC2.C2 (VDD), IC3.3 (VDDIO), IC3.7 (VDD), IC3.10 (CSB), IC9.E2 (VOUT_1), IC9.E3 (VOUT_2), J2.1, Q1.2 (S), R5.2, R7.2, R8.2, R17.1, R18.1, R_PWR_EPD.2, TP_3.3V.TP, TP_3V3.TP, U1.P$A22 (VDD), U1.P$AD14 (VDD), U1.P$AD23 (VDD), U1.P$B1 (VDD), U1.P$W1 (VDD), U1.P$Y2 (VDDH)
ALERT: U1.P$J24 (P0.10/NFC2), U3.5 (!ALERT)
D+: D3.4 (I/O2_2), U1.P$AD6 (D+)
D-: D3.6 (I/O1_2), U1.P$AD4 (D-)
DEC1: C5.1, U1.P$C1 (DEC1)
DEC3: C11.1, U1.P$D23 (DEC3)
DEC4_6: C10.1, C15.1, C16.1, L3.2, U1.P$B5 (DEC4), U1.P$E24 (DEC6)
DN: D3.1 (I/O1_1), J4.A7 (DN1), J4.B7 (DN2)
DP: D3.3 (I/O2_1), J4.A6 (DP1), J4.B6 (DP2)
EPD_3V3: C1-EP-DR.1, EPD_C5.2, J1.15, J1.16, L5.2, Q1.3 (D)
EPD_BUSY: J1.9, U1.P$AD12 (P0.17)
EPD_CS: J1.12, U1.P$K2 (P0.05/AIN3)
EPD_DC: J1.11, U1.P$AD10 (P0.15)
EPD_RST: J1.10, U1.P$AC11 (P0.16)
GDR: J1.2, Q3.1 (G), R2_EP_DR.2
GND: C1.2, C1-EP-DR.2, C2.2, C3.2, C4.2, C5.2, C6.2, C7.2, C8.2, C9.2, C10.2, C11.2, C12.2, C13.2, C14.2, C15.2, C16.2, C17.1, C18.1, C19.2, C20.2, C21.2, C22.2, C23.1, C24.1, C25.2, C27.1, C29.1, C30.1, C31.1, C32.1, C33.2, C34.1, C37.1, C38.1, C39.1, C42.1, C43.2, D3.2 (GND), D4.1 (K), EPD_C1.1, EPD_C2.1, EPD_C5.1, EPD_C6.1, EPD_C7.1, EPD_C8.1, EPD_C9.1, EPD_C10.1, EPD_C11.1, EPD_C12.1, IC1.D2 (GND), IC2.B1 (IN/TRIG), IC2.B3 (GND), IC3.8 (GNDIO), IC3.9 (GND), IC9.B1 (VSEL), IC9.C1 (AGND), IC9.C2 (PGND_1), IC9.C3 (PGND_2), J1.8, J1.17, J1.MP1, J1.MP2, J2.3, J2.5, J4.A1_B12 (GND), J4.A12_B1 (GND), J4.SH1 (SHIELD), J4.SH2 (SHIELD), J4.SH3 (SHIELD), J4.SH4 (SHIELD), R1_USB.1, R2_EP_DR.1, R2_USB.2, R3.1, R9.1, R_TYPE_SEL.1, SJ1.1, SW_DN.1, SW_ENT.1, SW_UP.1, TP_BAT_GND.TP, TP_GND.TP, U1.P$74 (VSS_PAD), U1.P$75 (VSS_PAD), U1.P$76 (VSS_PAD), U1.P$77 (VSS_PAD), U1.P$78 (VSS_PAD), U1.P$79 (VSS_PAD), U1.P$80 (VSS_PAD), U1.P$81 (VSS_PAD), U1.P$82 (VSS_PAD), U1.P$83 (VSS_PAD), U1.P$84 (VSS_PAD), U1.P$85 (VSS_PAD), U1.P$86 (VSS_PAD), U1.P$87 (VSS_PAD), U1.P$88 (VSS_PAD), U1.P$89 (VSS_PAD), U1.P$90 (VSS_PAD), U1.P$B7 (VSS), U1.P$F23 (VSS_PA), U3.1 (CTG), U3.4 (GND), U3.6 (QSTRT), U3.9 (EP), X1.2, X1.4
HAPTIC_EN: IC2.A1 (EN), U1.P$U1 (P0.12)
IMU_INT1: IC3.5 (INT1), U1.P$N1 (P0.08)
IMU_INT2: IC3.6 (INT2), U1.P$P2 (P1.08)
LX1: IC9.B2 (SW1_1), IC9.B3 (SW1_2), L7.1
LX2: IC9.D2 (SW2_1), IC9.D3 (SW2_2), L7.2
MOSI: J1.14, U1.P$B13 (P0.03/AIN1)
unnamed: ANT1.1 (FEED), C4.1, C22.1, L1.2
unnamed: IC9.D1 (SCL), R4.2
unnamed: IC1.D1 (TS/MR), R9.2
unnamed: C2.1, U1.P$A23 (XC2), X1.3
unnamed: IC9.E1 (SDA), R2.2
unnamed: J4.A5 (CC1), R1_USB.2
unnamed: L2.2, L3.1
unnamed: IC3.1 (SDO), R3.2
unnamed: C1.1, U1.P$B24 (XC1), X1.1
unnamed: C3.1, L1.1, U1.P$H23 (ANT)
unnamed: C32.2, IC2.A2 (REG)
unnamed: C2-EP-DR.1, D2.1 (K), D4.2 (A)
unnamed: C9.1, U1.P$N24 (DEC5)
unnamed: R1_EP_DR.1, R_TYPE_SEL.2, SJ1.2
unnamed: C2-EP-DR.2, D5.2 (A), L5.1, Q3.3 (D)
unnamed: EPD_C2.2, J1.4
unnamed: EPD_C1.2, J1.5
unnamed: C20.1, U1.P$AC5 (DEC3V3)
unnamed: L2.1, U1.P$B3 (DCC)
unnamed: J4.B5 (CC2), R2_USB.1
unnamed: EPD_C6.2, J1.18
unnamed: EPD_C7.2, J1.19
unnamed: EPD_C8.2, J1.20
unnamed: EPD_C10.2, J1.22
unnamed: C13.1, U1.P$A18 (DEC2)
unnamed: EPD_C12.2, J1.24
OUT+: IC2.A3 (OUT+), TP_OP.TP
OUT-: IC2.C3 (OUT-), TP_ON.TP
P0.00/XL1: C17.2, U1.P$D2 (P0.00/XL1), X2.1
P0.01/XL2: C18.2, U1.P$F2 (P0.01/XL2), X2.2
P0.04: U1.P$J1 (P0.04/AIN2)
P0.09: U1.P$L24 (P0.09/NFC1)
P0.13: C30.2, R5.1, SW_UP.2
P0.14: C31.2, R8.1, SW_ENT.2
P0.19: U1.P$AC15 (P0.19)
P0.20: U1.P$AD16 (P0.20)
P0.21: U1.P$AC17 (P0.21)
P0.22: U1.P$AD18 (P0.22)
P0.23: U1.P$AC19 (P0.23)
P0.24: U1.P$AD20 (P0.24)
P0.25: U1.P$AC21 (P0.25)
P0.26: U1.P$G1 (P0.26)
P0.27: U1.P$H2 (P0.27)
P0.28: U1.P$B11 (P0.28/AIN4)
P0.29: U1.P$A10 (P0.29/AIN5)
P0.30: U1.P$B9 (P0.30/AIN6)
P0.31: U1.P$A8 (P0.31/AIN7)
P1.01: Q1.1 (G), R_PWR_EPD.1, U1.P$Y23 (P1.01)
P1.02: C29.2, R7.1, SW_DN.2, U1.P$W24 (P1.02)
P1.03: U1.P$V23 (P1.03)
P1.04: U1.P$U24 (P1.04)
P1.05: U1.P$T23 (P1.05)
P1.06: U1.P$R24 (P1.06)
P1.07: U1.P$P23 (P1.07)
P1.09: U1.P$R1 (P1.09)
P1.10: U1.P$A20 (P1.10)
P1.11: U1.P$B19 (P1.11)
P1.12: U1.P$B17 (P1.12)
P1.13: U1.P$A16 (P1.13)
P1.14: U1.P$B15 (P1.14)
P1.15: U1.P$A14 (P1.15)
PMIC_INT: IC1.A1 (!INT), U1.P$T2 (P0.11)
PO.13: U1.P$AD8 (P0.13)
PO.14: U1.P$AC9 (P0.14)
PREVGH: D5.1 (K), EPD_C9.2, J1.21
PREVGL: D2.2 (A), EPD_C11.2, J1.23
RESE: J1.3, Q3.2 (S), R1_EP_DR.2
RESET: J2.6, TP_RESET.TP, U1.P$AC13 (P0.18/RESET)
SCK: J1.13, U1.P$A12 (P0.02/AIN0)
SCL: IC1.B1 (SCL), IC2.C1 (SCL), IC3.12 (SCX), R4.1, R17.2, TP_SCL.TP, U1.P$M2 (P0.07), U3.7 (SCL)
SDA: IC1.C1 (SDA), IC2.B2 (SDA), IC3.2 (SDX), R2.1, R18.2, TP_SDA.TP, U1.P$L1 (P0.06), U3.8 (SDA)
SWDCLK: J2.4, TP_SWDCLK.TP, U1.P$AA24 (SWDCLK)
SWDIO: J2.2, TP_SWDIO.TP, U1.P$AC24 (SWDIO)
SWO: TP_SWO.TP, U1.P$AD22 (P1.00)
VBAT: C27.2, C37.2, IC1.C2 (BAT), TP_VBAT.TP, U3.2 (CELL), U3.3 (VDD)
VBUS: C21.1, C38.2, C42.2, C43.1, D3.5 (VBUS), IC1.A2 (IN), J4.A4_B9 (VBUS), J4.A9_B4 (VBUS), U1.P$AD2 (VBUS)
VREG: C23.2, C24.2, C39.2, IC1.B2 (SYS), IC9.A1 (EN), IC9.A2 (VIN_1), IC9.A3 (VIN_2), TP_VREG.TP

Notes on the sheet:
LiPo Charger
DC/DC
IMU
SWD
E-Paper Drive Circuit
E-Paper Display Connector
Fuel Gauge
Haptic Driver
Buttons
USB C Connector & ESD Protection

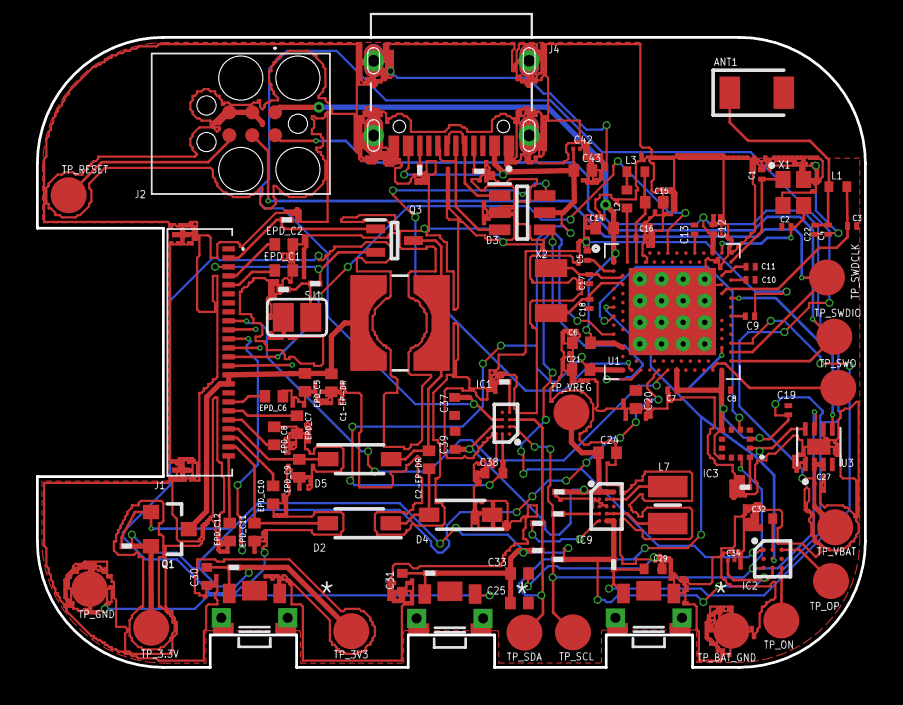
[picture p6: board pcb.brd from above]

Board: 2 copper layers, 46.0 x 35.0 mm, 105 parts (0 on the bottom side), 70 nets.

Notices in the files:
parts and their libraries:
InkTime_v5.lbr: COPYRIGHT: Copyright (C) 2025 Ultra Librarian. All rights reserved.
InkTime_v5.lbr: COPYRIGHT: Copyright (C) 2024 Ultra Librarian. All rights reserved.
